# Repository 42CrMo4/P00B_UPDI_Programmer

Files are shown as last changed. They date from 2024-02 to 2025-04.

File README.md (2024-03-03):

# UPDI Programmer

A UPDI Programmer to use the Würth Redfit Skedd Connector and a switch for UPDI and TX of the MCU.

### Goal & Status

Goal: Prototype
Status: implementation

#### Definitions
| undefined | learn | prototype | 80-20-rule | polished Product |
|---|---|---|---|---|
| not known what the project will bring | personally learn something new (function, design, process) otherwise no usefull outcome expected | a working prototype or mvp | 80% outcome with 20% effort. Dont expect a finished product. | - |

| idea | design | implementation | testing | finished |
|---|---|---|---|---|
| brainstorming workflow | putting together a goal list, architecture, hig level | schematic, pcb | | |

## Todo

## Description. 

| Font | Back |
|---|---|
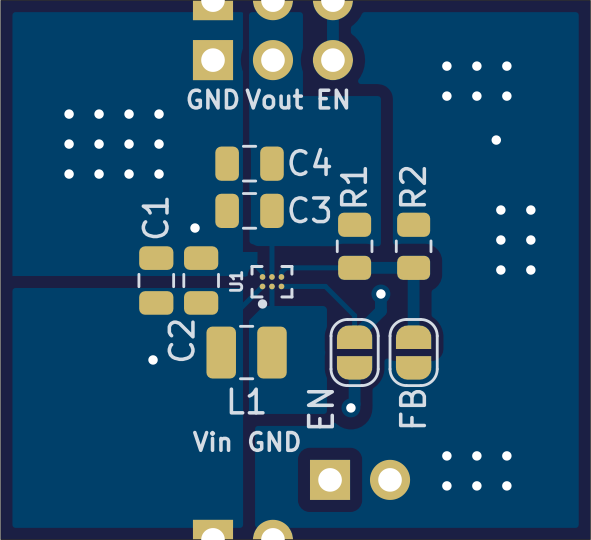
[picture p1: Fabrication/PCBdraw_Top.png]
PCB Top design
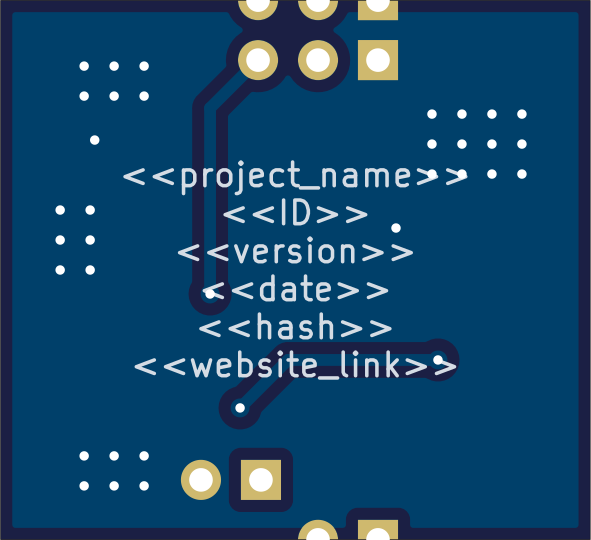
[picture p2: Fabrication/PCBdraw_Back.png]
PCB Back design
|  |  |

Link to the current BOM

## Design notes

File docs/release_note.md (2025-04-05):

| Font | Back |
| --- | --- |
|PCB Top design|PCB Back design|

Version bump due to changed pinout of the J1 connector. 
Otherwise only small updates. 
Stencil of Version v1.0 is still valid but with the downside of USB Type-C Tabs not geting soldered. 

New
-

Changes
* Keep Signal voltage for TS3USB in specified operational condition (now i will work at 5V Level too)
* Add missing Pin 1 markers
* Update USB Type-C Footprint to include correct Stencil Data (Tabs had no solder - needed to be soldered by hand)
* exclude the unneeded switch from BOM. Is not needed due to the automatic switch over
* minor refactoring of Schematic and PCB

Breaking Changes
* Pinout of the J1 connector (changed to GLL1 Standard)

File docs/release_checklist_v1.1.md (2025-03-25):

Check before releasing and/or submitting to FAB
- [x] DRC/ERC passing
- [x] check for unconnected Traces
- [x] Groundplanes (newly) filled
- [ ] Dimension Outline
- [ ] Mounting Holes
- [ ] Clearance for Connectors
- [ ] Clearance for Housing
- [ ] Clearance for generell
- [ ] Component Labels
- [ ] Labels not over VIA or Holes etc. 
- [ ] Label Important (All) Pins — Both Sides
- [ ] Revision number of Checklist will match the Git tag
- [x] Double check the final files
- [x] Fill Changelog (release_note.md)
- [ ] projekt.properties filled correctly
- [ ] Weblink / version / Date / name present SCH
- [ ] Weblink / version / Date / name present PCB
- [ ] Power Trace correct width
- [ ] decoupling capacitors present
- [ ] component orientation correct (MCU, Diod, etc)

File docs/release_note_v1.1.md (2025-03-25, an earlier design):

| Font | Back |
| --- | --- |
|PCB Top design|PCB Back design|

Fix critical Bugs with the serialUPDI and the power cycle Switch. 
The SerialUPDI resitor was incorrectly placed on the RX line and not on the TX line.
Pins for the power cycle pushbutton were wired incorrectly, this is now corrected.  

New
* Add DTR automatic switching
* Add Testpoints for ch340 pins

Changes
* correct power cycle switch pins
* correct serialUPDI resistor
* switch outputs of TS3USB30RSWR (D1<->D2) because of DTR signal Levels

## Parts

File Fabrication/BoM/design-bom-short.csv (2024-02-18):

Row | Description | Part | References | Value | Footprint | Quantity Per PCB | Status | Datasheet | STANDARD | PARTREV | MAXIMUM_PACKAGE_HEIGHT | MANUFACTURER
1 | Unpolarized capacitor, small symbol | C_Small | C1 C2 C3 C4 | C_Small | C_0805_2012Metric | 4 |  | ~
2 | Generic connector, single row, 01x02, script generated (kicad-library-utils/schlib/autogen/connector/) | Conn_01x02 | J1 J2 | Conn_01x02 | PinHeader_1x02_P2.54mm_Vertical | 2 |  | ~
3 | Generic connector, single row, 01x03, script generated (kicad-library-utils/schlib/autogen/connector/) | Conn_01x03 | J3 J4 | Conn_01x03 | PinHeader_1x03_P2.54mm_Vertical | 2 |  | ~
4 | Inductor, small symbol | L_Small | L1 | L_Small | L_1008_2520Metric | 1 |  | ~
5 | Resistor, small symbol | R_Small | R1 R2 | R_Small | R_0805_2012Metric | 2 |  | ~
6 |  | TPS61099YFFT | U1 | TPS61099YFFT | BGA6N40P3X2_122X88X62N | 1 |  |  | IPC 7351B | K | 0.625mm | Texas Instruments

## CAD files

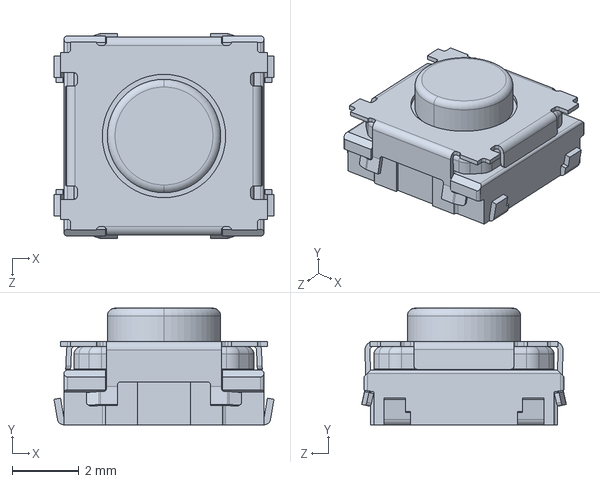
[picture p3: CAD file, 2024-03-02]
3d-models/EVPBFAC1A000.STEP
6.60 x 3.50 x 6.14 mm

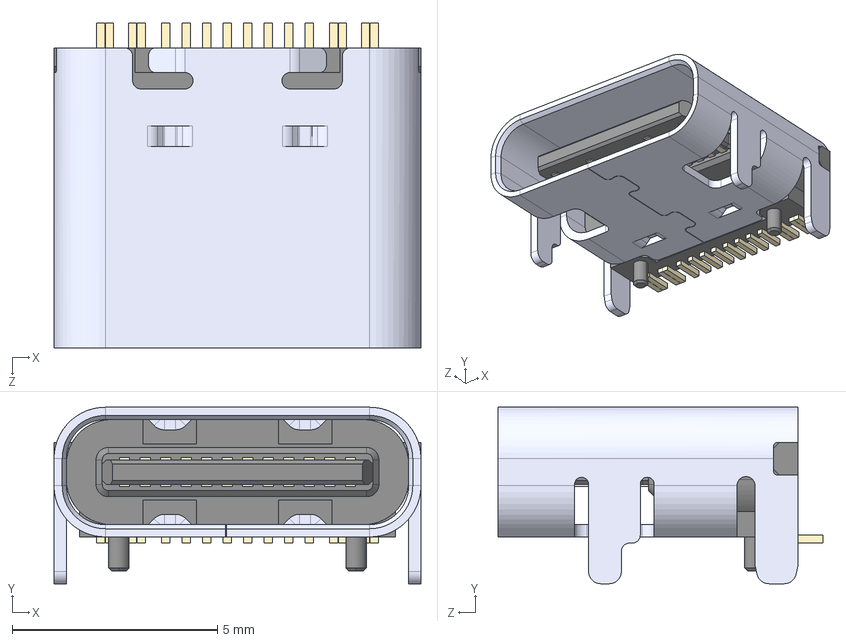
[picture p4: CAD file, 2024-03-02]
3d-models/TYPE-C-31-M-12.step
8.94 x 4.30 x 7.90 mm

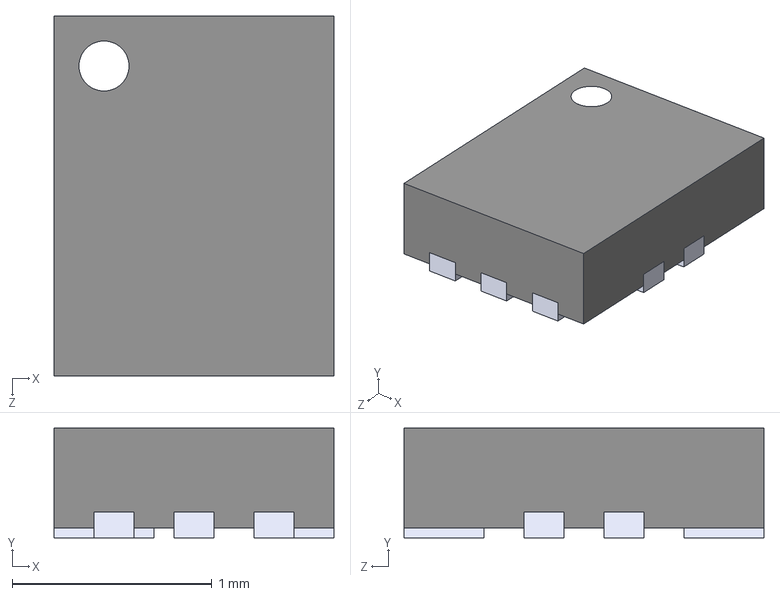
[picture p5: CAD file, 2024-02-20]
3d-models/TS3USB30RSWR.step
1.40 x 0.55 x 1.80 mm

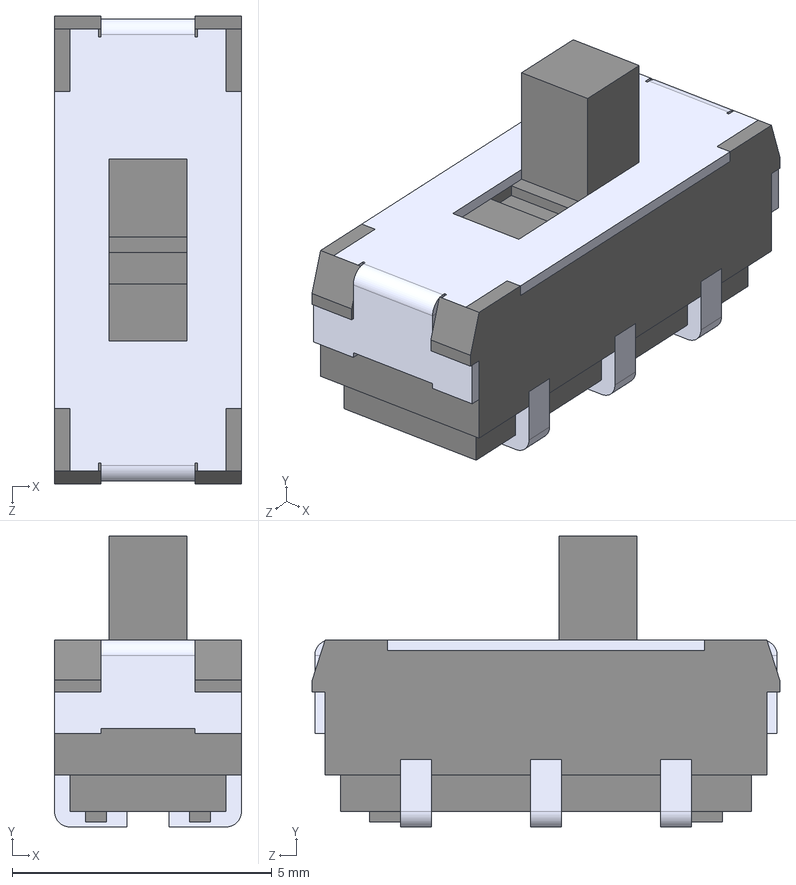
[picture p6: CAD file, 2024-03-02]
3d-models/JS202011JCQN.step
3.60 x 5.60 x 9.00 mm

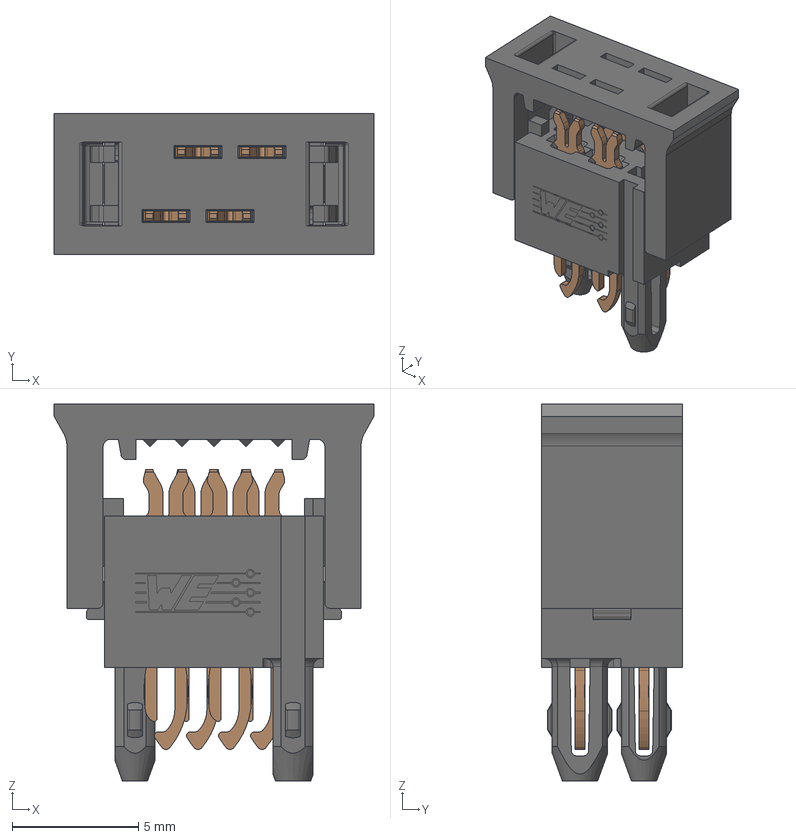
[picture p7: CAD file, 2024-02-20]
3d-models/490107670412.step
12.7 x 5.60 x 15.0 mm
CT422_00.4.1.1_0 x 4
BS698_4_00.4_0000_0
BS697_4_00.6_0000_0

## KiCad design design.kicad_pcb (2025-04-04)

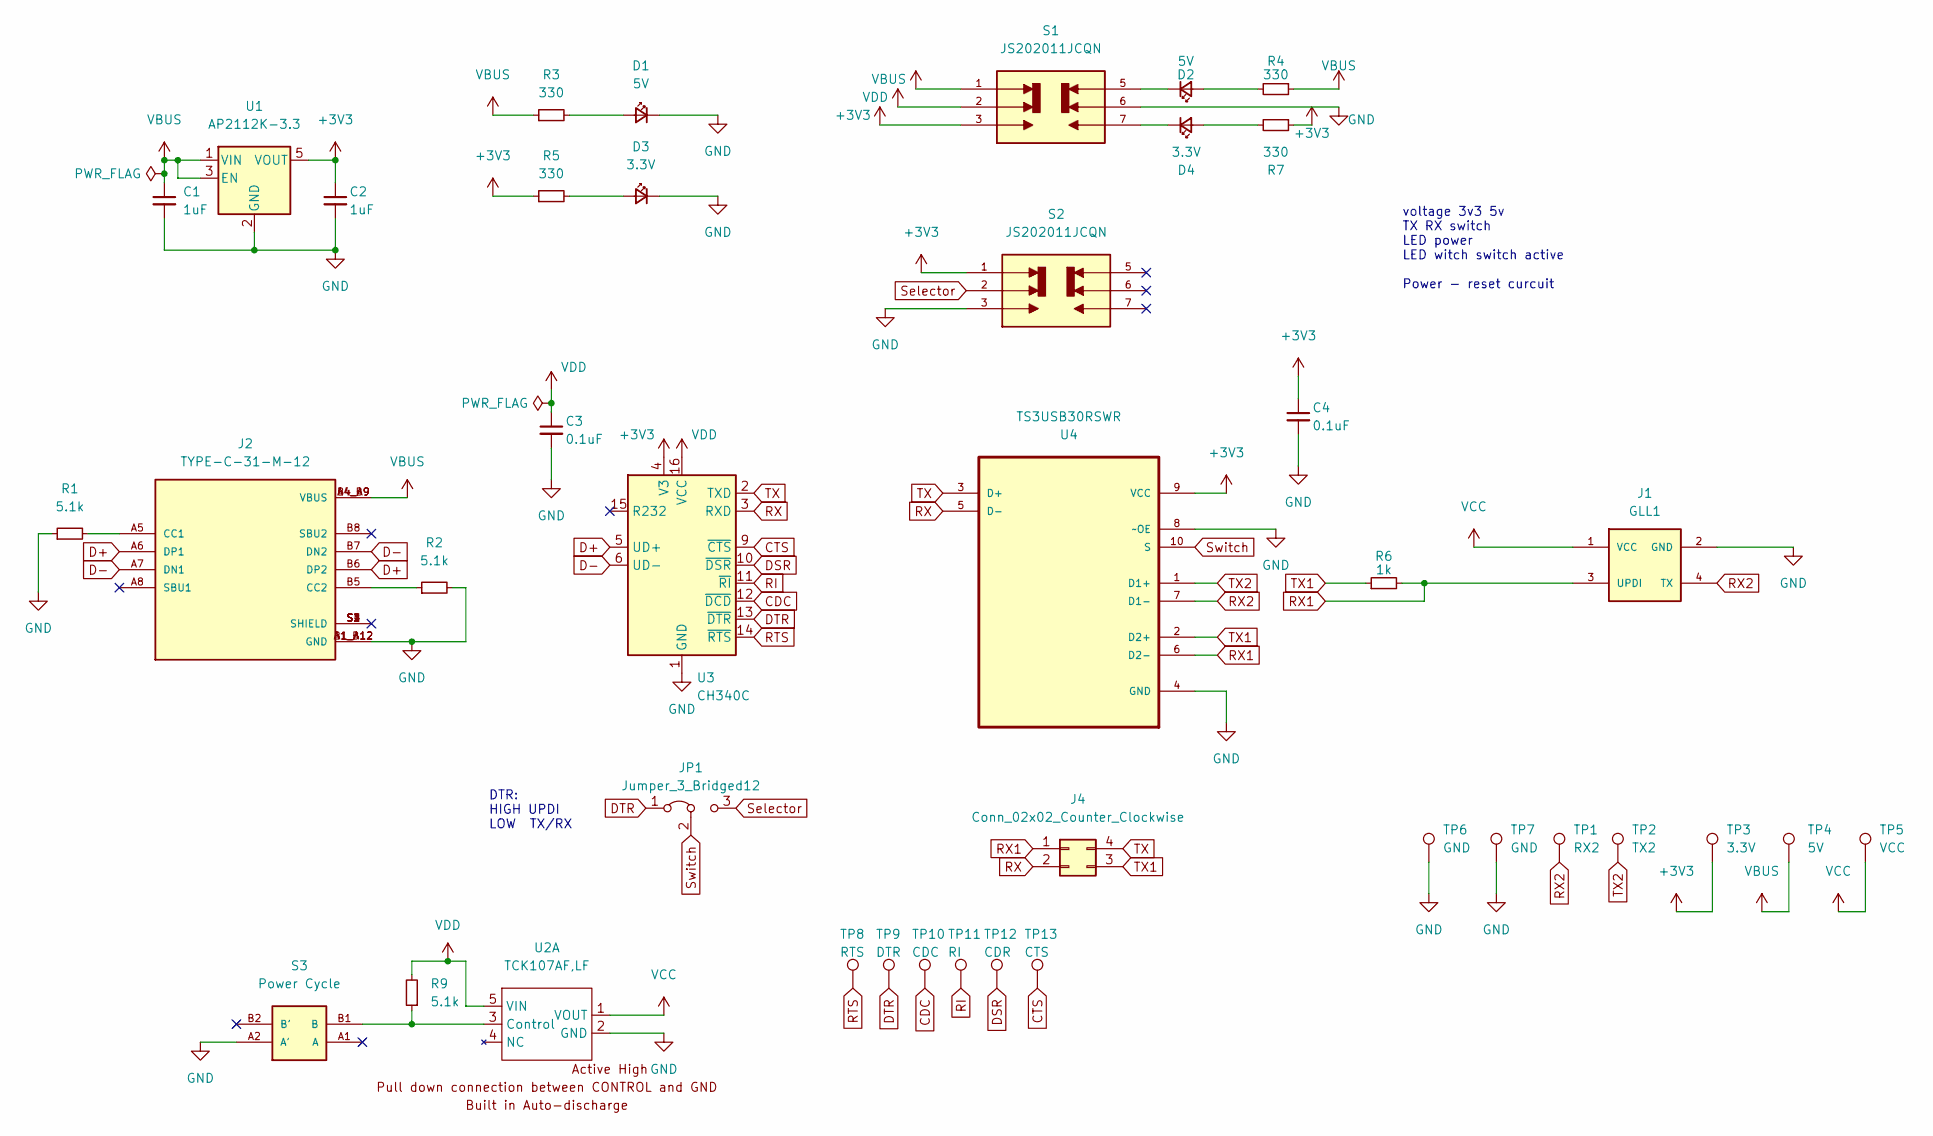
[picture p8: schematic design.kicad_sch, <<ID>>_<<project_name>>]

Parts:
C1, C2: 1uF; C_0805_2012Metric
C3, C4: 0.1uF; C_0805_2012Metric
D1, D2: 5V; LED_0805_2012Metric
D3, D4: 3.3V; LED_0805_2012Metric
J1: GLL1
J2: TYPE-C-31-M-12; TYPE-C-31-M-12_HRO_TYPE-C-31-M-12; PARTREV 2020.12.08
J4: Conn_02x02_Counter_Clockwise; PinHeader_2x02_P2.54mm_Vertical
JP1: Jumper_3_Bridged12; SolderJumper-3_P1.3mm_Bridged12_Pad1.0x1.5mm_NumberLabels
R1, R2, R9: 5.1k; R_0805_2012Metric
R3, R4, R5, R7: 330; R_0805_2012Metric
R6: 1k; R_0805_2012Metric
S1, S2: JS202011JCQN; SW_JS202011JCQN; PARTREV 11 Nov 19
S3: Power Cycle; EVP-BFAC1A000_EVPBFAC1A000; MOUSER_PART_NUMBER 667-EVP-BFAC1A000
TP1: RX2; TestPoint_Pad_D2.0mm
TP2: TX2; TestPoint_Pad_D2.0mm
TP3: 3.3V; TestPoint_Pad_D2.0mm
TP4: 5V; TestPoint_Pad_D2.0mm
TP5: VCC; TestPoint_Pad_D2.0mm
TP6, TP7: GND; TestPoint_Pad_D1.0mm
TP8: RTS; TestPoint_Pad_D1.0mm
TP9: DTR; TestPoint_Pad_D1.0mm
TP10: CDC; TestPoint_Pad_D1.0mm
TP11: RI; TestPoint_Pad_D1.0mm
TP12: CDR; TestPoint_Pad_D1.0mm
TP13: CTS; TestPoint_Pad_D1.0mm
U1: AP2112K-3.3; SOT-23-5
U2: TCK107AF,LF; SOT-23-5
U3: CH340C; SOIC-16_3.9x9.9mm_P1.27mm
U4: TS3USB30RSWR; TS3USB30RSWR_QFN40P140X180X55-10N; MPN TS3USB30RSWR

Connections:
+3V3: C2.1, C4.1, R5.1, R7.1, S1.3, S2.1, TP3.1, U1.5 (VOUT), U3.4 (V3), U4.9 (VCC)
CDC: TP10.1, U3.12 (~DCD)
CTS: TP13.1, U3.9 (~CTS)
D+: J2.A6 (DP1), J2.B6 (DP2), U3.5 (UD+)
D-: J2.A7 (DN1), J2.B7 (DN2), U3.6 (UD-)
DSR: TP12.1, U3.10 (~DSR)
DTR: JP1.1 (A), TP9.1, U3.13 (~DTR)
GND: C1.2, C2.2, C3.2, C4.2, D1.1 (K), D3.1 (K), J1.2 (GND), J2.A1_B12 (GND), J2.B1_A12 (GND), R1.1, R2.2, S1.6, S2.3, S3.A2 (A'), TP6.1, TP7.1, U1.2 (GND), U2.2 (GND), U3.1 (GND), U4.4 (GND), U4.8 (~OE)
unnamed: D1.2 (A), R3.2
unnamed: D2.1 (K), S1.5
unnamed: D2.2 (A), R4.2
unnamed: D3.2 (A), R5.2
unnamed: D4.1 (K), S1.7
unnamed: D4.2 (A), R7.2
unnamed: J2.A5 (CC1), R1.2
unnamed: J2.B5 (CC2), R2.1
unnamed: R9.1, S3.B1 (B), U2.3 (Control)
RI: TP11.1, U3.11 (~RI)
RTS: TP8.1, U3.14 (~RTS)
RX: J4.2, U3.3 (RXD), U4.5 (D-)
RX1: J1.3 (UPDI), J4.1, R6.2, U4.6 (D2-)
RX2: J1.4 (TX), TP1.1, U4.7 (D1-)
Selector: JP1.3 (B), S2.2
Switch: JP1.2 (C), U4.10 (S)
TX: J4.4, U3.2 (TXD), U4.3 (D+)
TX1: J4.3, R6.1, U4.2 (D2+)
TX2: TP2.1, U4.1 (D1+)
VBUS: C1.1, J2.A4_B9 (VBUS), J2.B4_A9 (VBUS), R3.1, R4.1, S1.1, TP4.1, U1.1 (VIN), U1.3 (EN)
VCC: J1.1 (VCC), TP5.1, U2.1 (VOUT)
VDD: C3.1, R9.2, S1.2, U2.5 (VIN), U3.16 (VCC)

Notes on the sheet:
DTR: HIGH UPDI LOW TX/RX
voltage 3v3 5v TX RX switch LED power LED witch switch active Power - reset curcuit

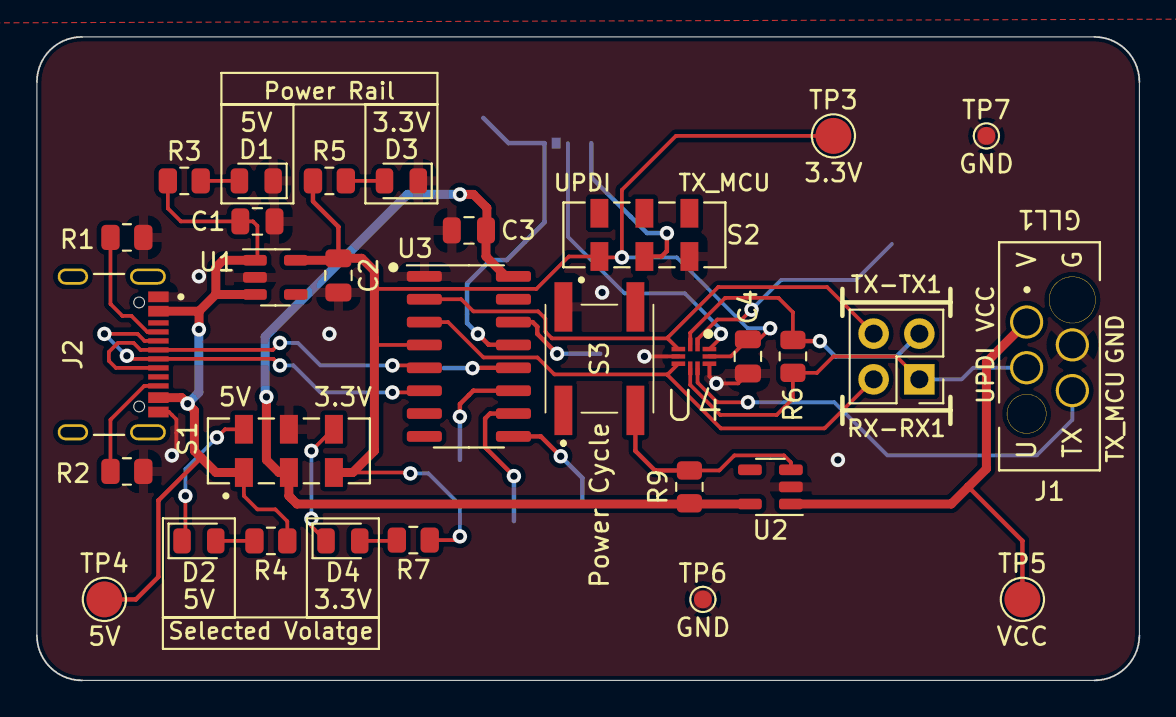
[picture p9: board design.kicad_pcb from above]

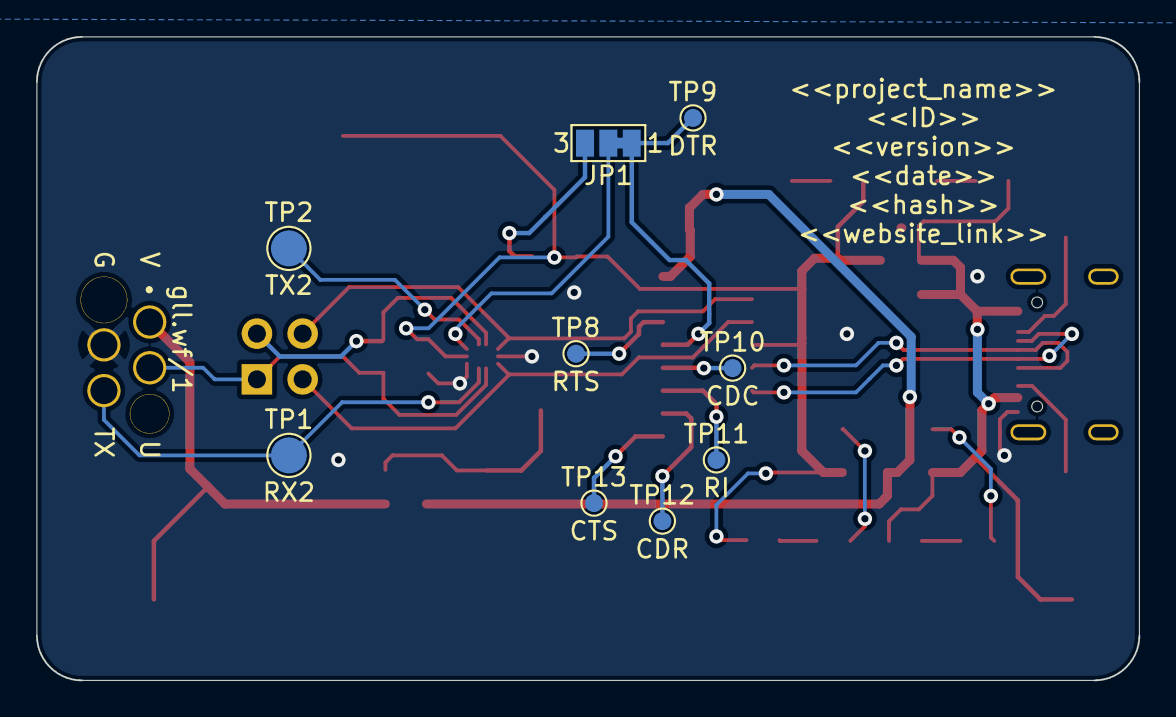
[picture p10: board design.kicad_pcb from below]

Board: 2 copper layers, 61.2 x 35.8 mm, 40 parts (9 on the bottom side), 30 nets.

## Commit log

2024-02-19 use only external WF for BOM
2024-02-20 play around
    [design.kicad_pcb, design.kicad_sch]
2024-02-20 add steps
    [490107670412.step, TS3USB30RSWR.step]
2024-02-23 add components
    [design.kicad_pcb, design.kicad_sch]
2024-03-02 small changes
    [design.kicad_pcb, design.kicad_sch]
2024-03-02 update for logo
    [design.kicad_pcb, design.kicad_sch]
2024-03-02 remove logo
    [design.kicad_pcb, design.kicad_sch]
2024-03-02 add IPN
    [design.kicad_pcb, design.kicad_sch]
2025-03-24 correct power cycle switch pins
    internally connected pins where used instead of switched pins.
    [design.kicad_sch]
2025-03-24 correct serialUPDI resistor
    the correct way is in the TX line
    add picture of serialUPDI wiring
    [design.kicad_sch]
2025-03-24 PCB fix serialUPDI resistor and power switch pins
    [design.kicad_pcb]
2025-03-25 Add DTR automatic switching and Testpoints
    [design.kicad_pcb, design.kicad_sch]
2025-03-25 change silkscreen
    [design.kicad_pcb]
2025-03-25 update PCB Diff
    all layers and unfill zones
2025-03-25 make change TX1/RX1 and TX2/RX2 more visible in DIFF output
    [design.kicad_sch]
2025-04-04 Update footprint from Library - Stencil Data
    Tabs of the Type-C connector had no solder paste and are prone to disconnect.
    [design.kicad_pcb]
2025-04-04 Add Pin1 marker
    CH340C
    TS3USB30RSWR
    [design.kicad_pcb]
2025-04-04 Breaking: Update to GLL1 connector standard
    gll.wf/1
    Pinout changed for J1
    [design.kicad_pcb, design.kicad_sch]
2025-04-04 exclude unneeded switch from BOM
    As long the automatic switchover works this switch is not needed and without cutting JP1 it has no affect.
    [design.kicad_pcb]
2025-04-04 Typo in path of 3D model
    [design.kicad_pcb]
2025-04-04 refactor vias and silkscreen
    [design.kicad_pcb]
2025-04-04 make each shield pin of type-c unique
    to get rid of DRC errors
    [design.kicad_pcb]
2025-04-04 refactor 3 point interconnect in schematic
    [design.kicad_sch]
2025-04-05 keep Signal voltage for TS3USB below max.
    I/O signals are at 3.3V and do not withstand 5V
    [design.kicad_sch]
